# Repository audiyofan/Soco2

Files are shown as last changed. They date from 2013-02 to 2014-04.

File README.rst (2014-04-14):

=========================
SOCO2 PUSH PULL AMPLIFIER
=========================

Project authors:

- Pascal Benoist
- Grégoire Hubert
- Christophe Dedessus Les Moutier
- Yves Monmagnon

See http://audiyofan.org 

More information here http://www.audiyofan.org/forum/viewtopic.php?f=60&t=8371

Presentation
------------

Soco2 is a valve push-pull type amplifier delivering 10W in 8ohms with a low output impedance. It uses cheap Russian 6C19Π low impedance triodes as output valve and can be used without global feedback.

The built_version
------------------

The project was made on printed circuit board ( all files are included in Kicad folder )

This version does not use the PNK,

And the 6S19P's CCS is decoupled and has zener protection that prevents slippage cathode voltage on the higer swing

Power is succinct and yet respects the constants time

Local feedback of -1 dB, improve the damping factor

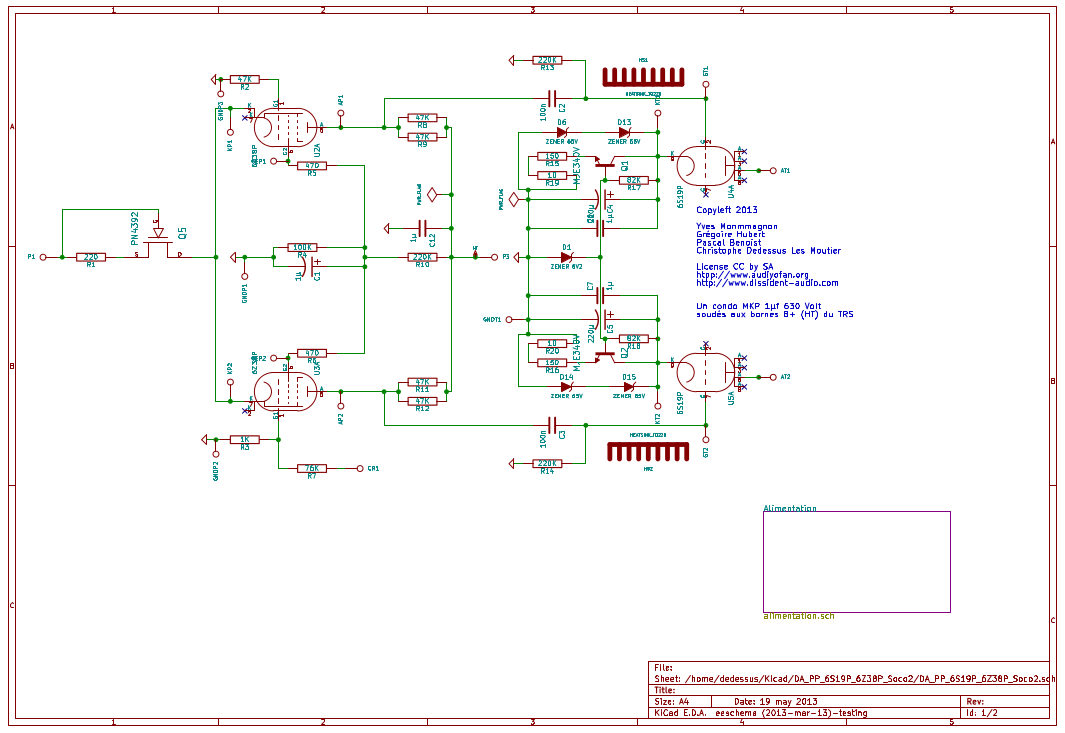
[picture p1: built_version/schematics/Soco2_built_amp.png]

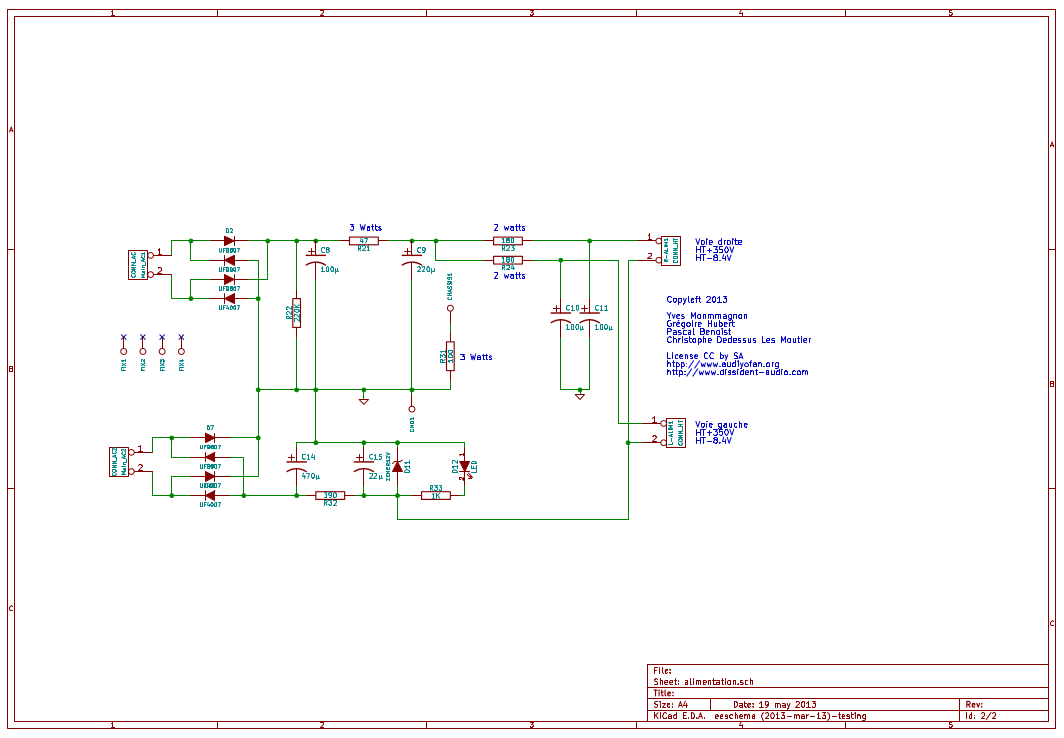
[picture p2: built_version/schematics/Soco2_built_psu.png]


Warning
-------

This schematic implies the use of **lethal voltages**. Maximum precautions must be observed when working with this kind of high voltages. Authors are **not** responsible in any way for any problems, damages or injuries that would result in the making of the work and / or use of this schematic (see LICENCE file).

Results
-------

Realisations emitted very natural, detailed and transparent sound with nice deep bass using speakers as low as 90dB/W/m. Measures showed -74dB THD for 1/2W output and -65dB THD for 1W (H2 and H3) with matched tubes. Output can reach 13W with -40dB THD in 8Ω. 
    
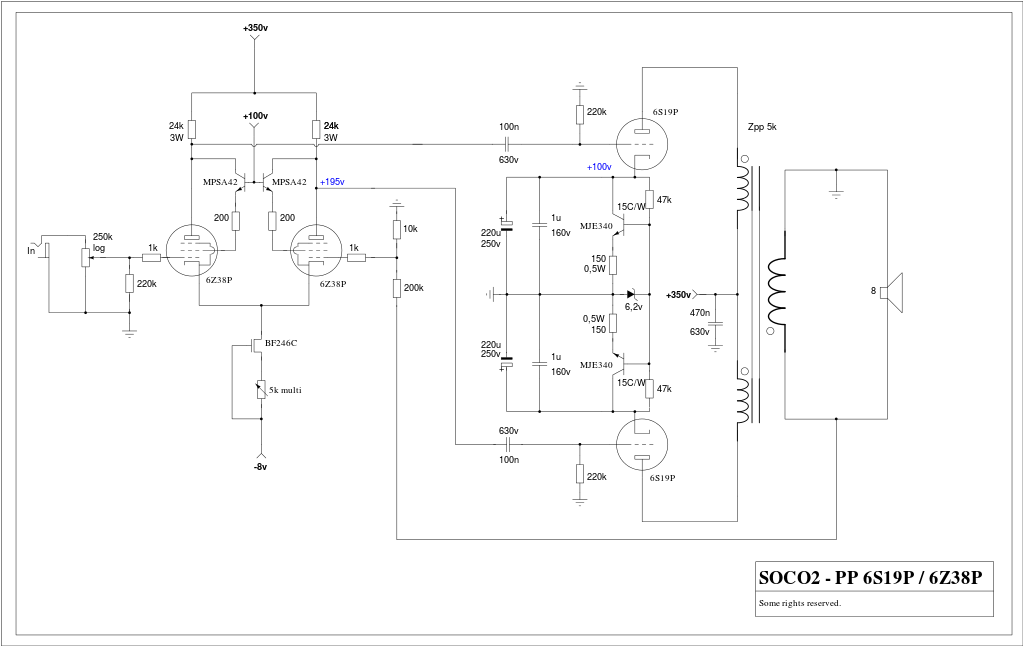
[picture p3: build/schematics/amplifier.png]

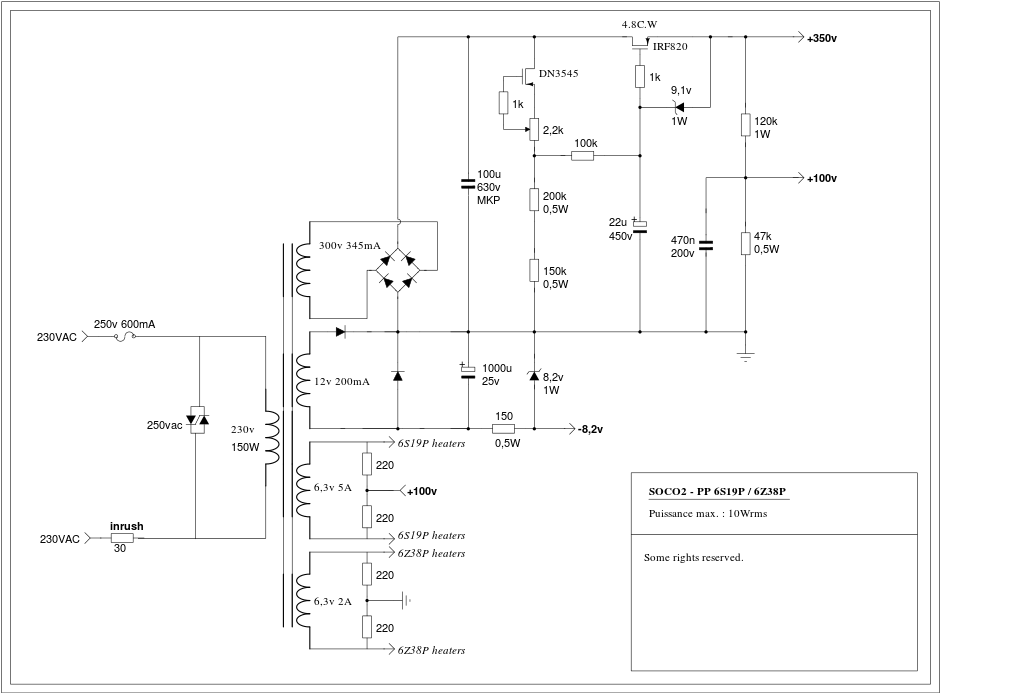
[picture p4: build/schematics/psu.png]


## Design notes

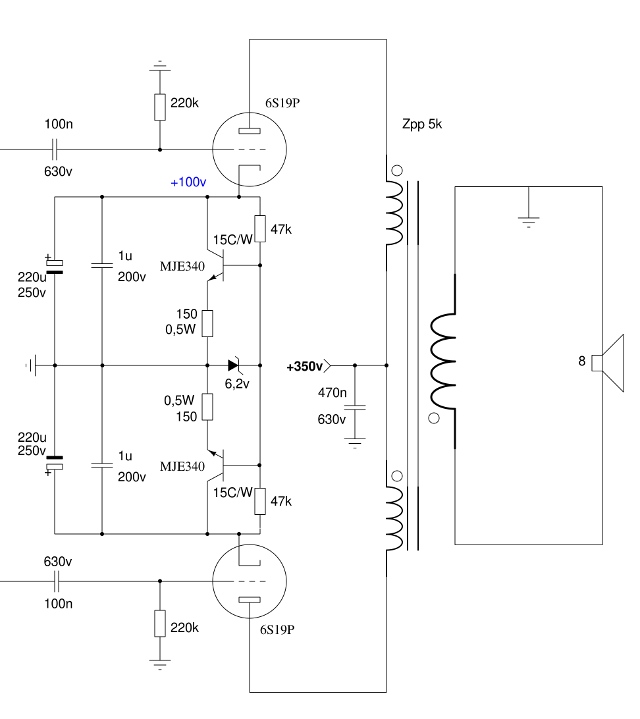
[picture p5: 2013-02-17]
build/schematics/power.png

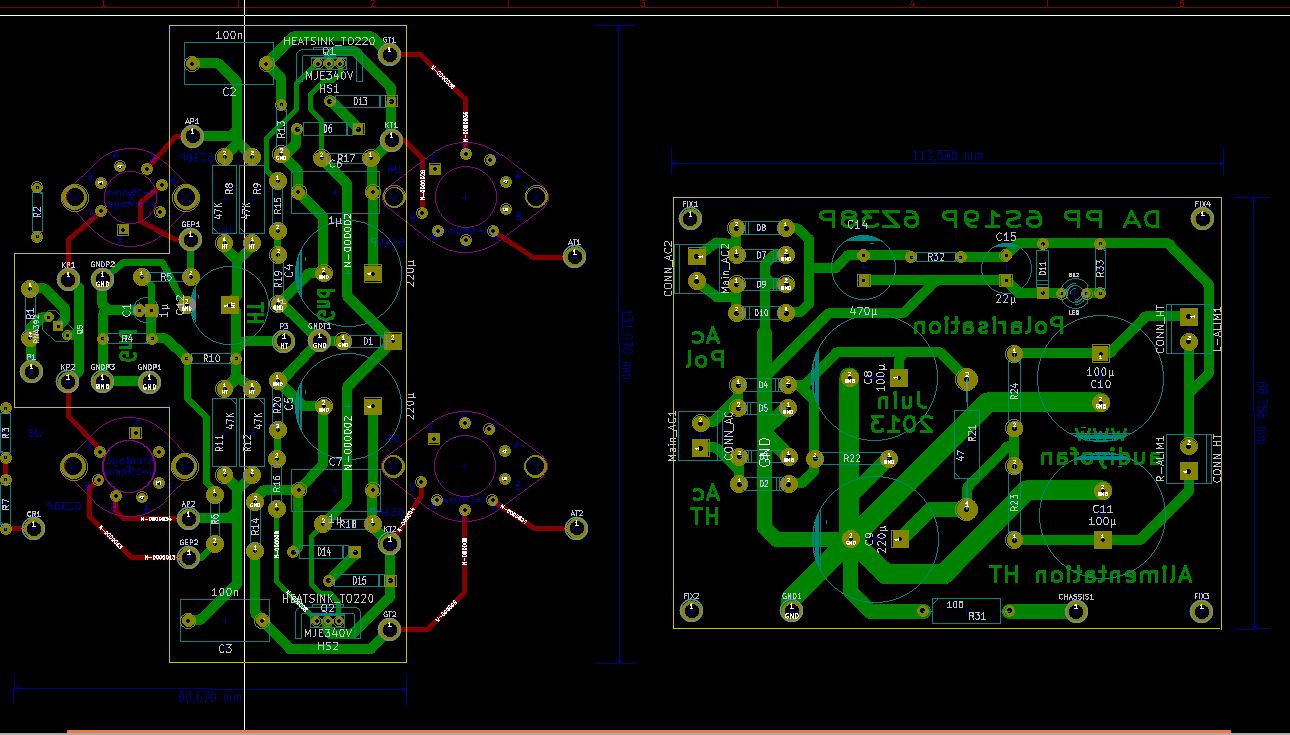
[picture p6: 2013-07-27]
built_version/Images/DA_Soco2_PCB.png

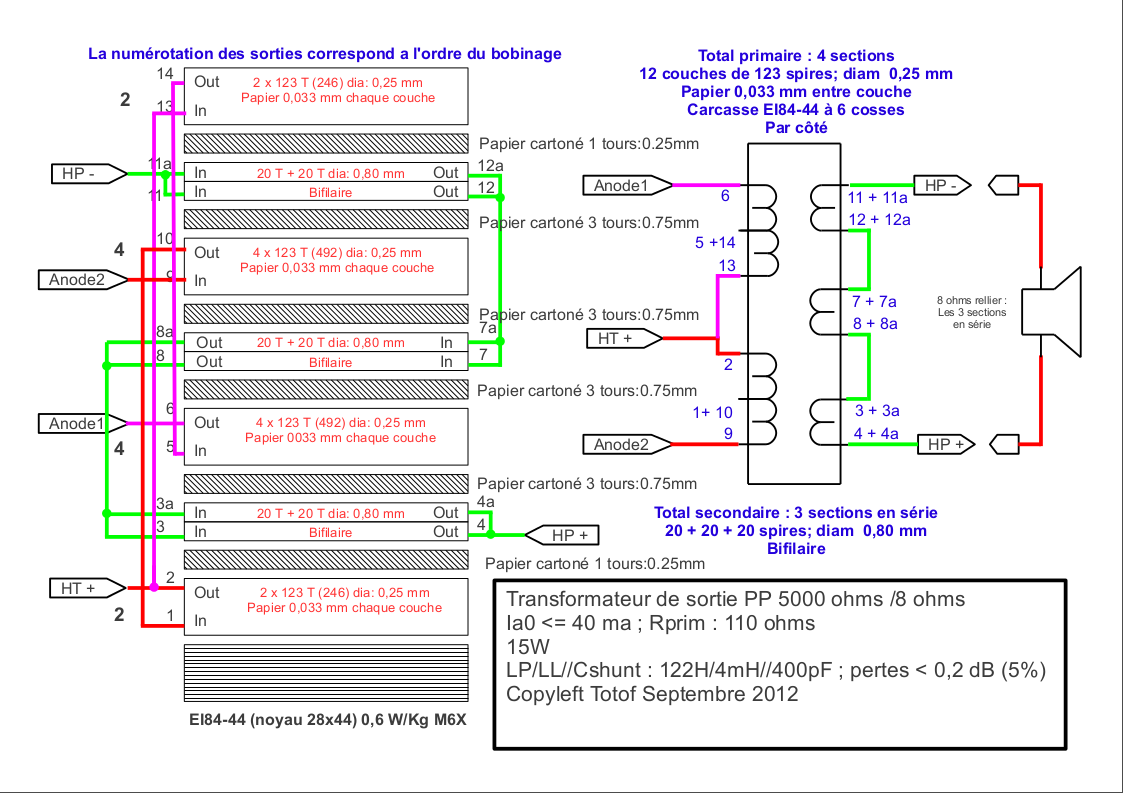
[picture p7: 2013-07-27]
built_version/Images/Calepinage_TRS_6S19P_6Z38P_final.png

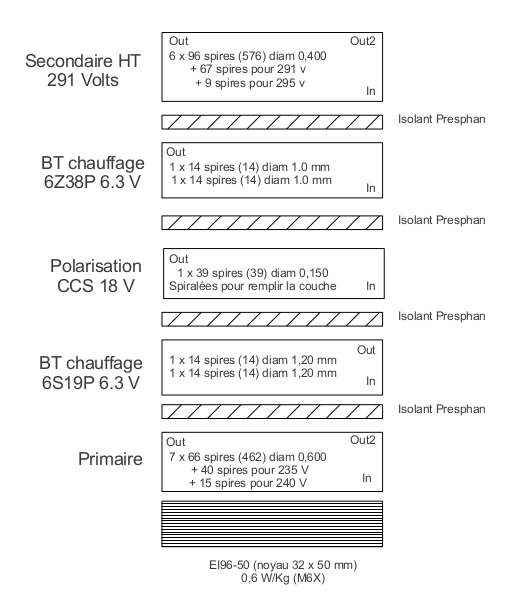
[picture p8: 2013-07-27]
built_version/Images/Calepinage TA .png

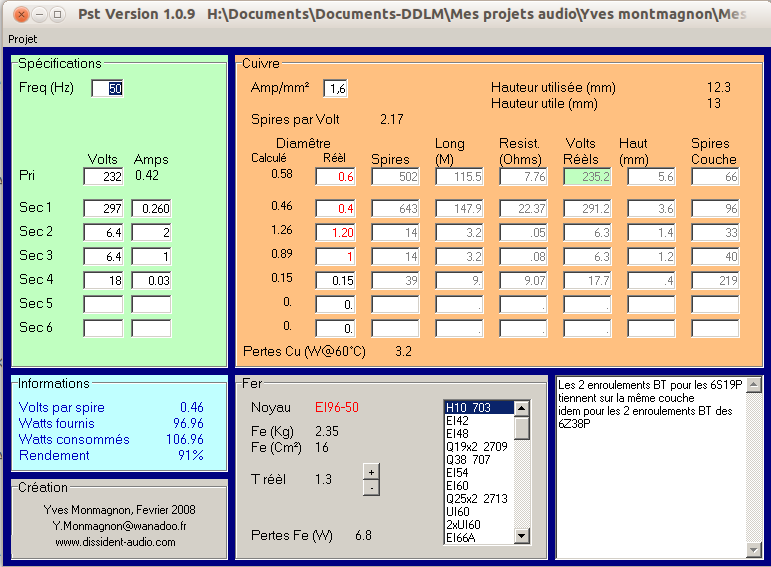
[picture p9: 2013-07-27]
built_version/Images/TA DA PP 6S19P 6Z38P PSX.png

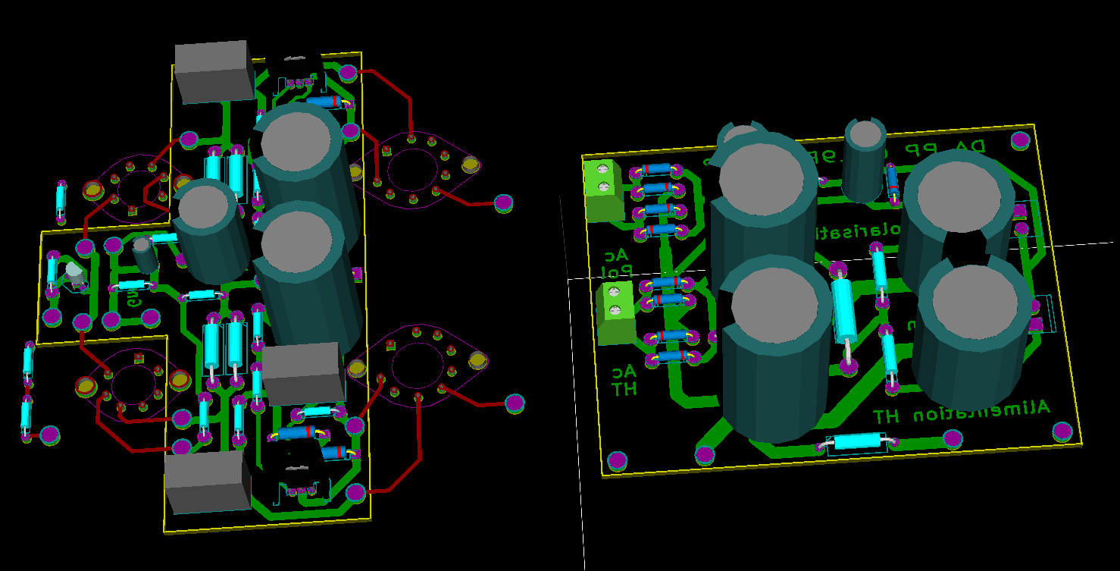
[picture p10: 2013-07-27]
built_version/Images/DA_Soco2_3D.png

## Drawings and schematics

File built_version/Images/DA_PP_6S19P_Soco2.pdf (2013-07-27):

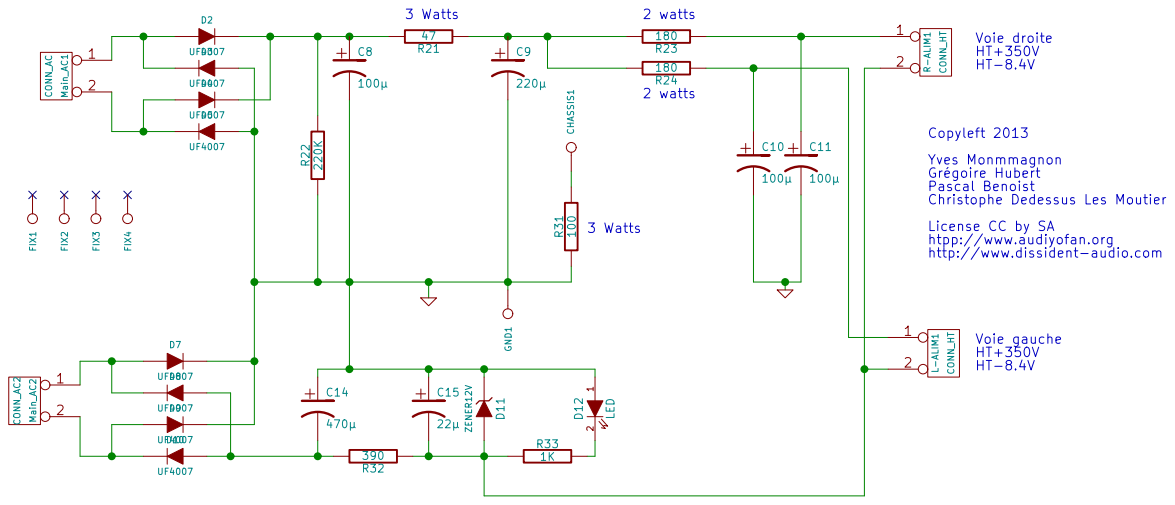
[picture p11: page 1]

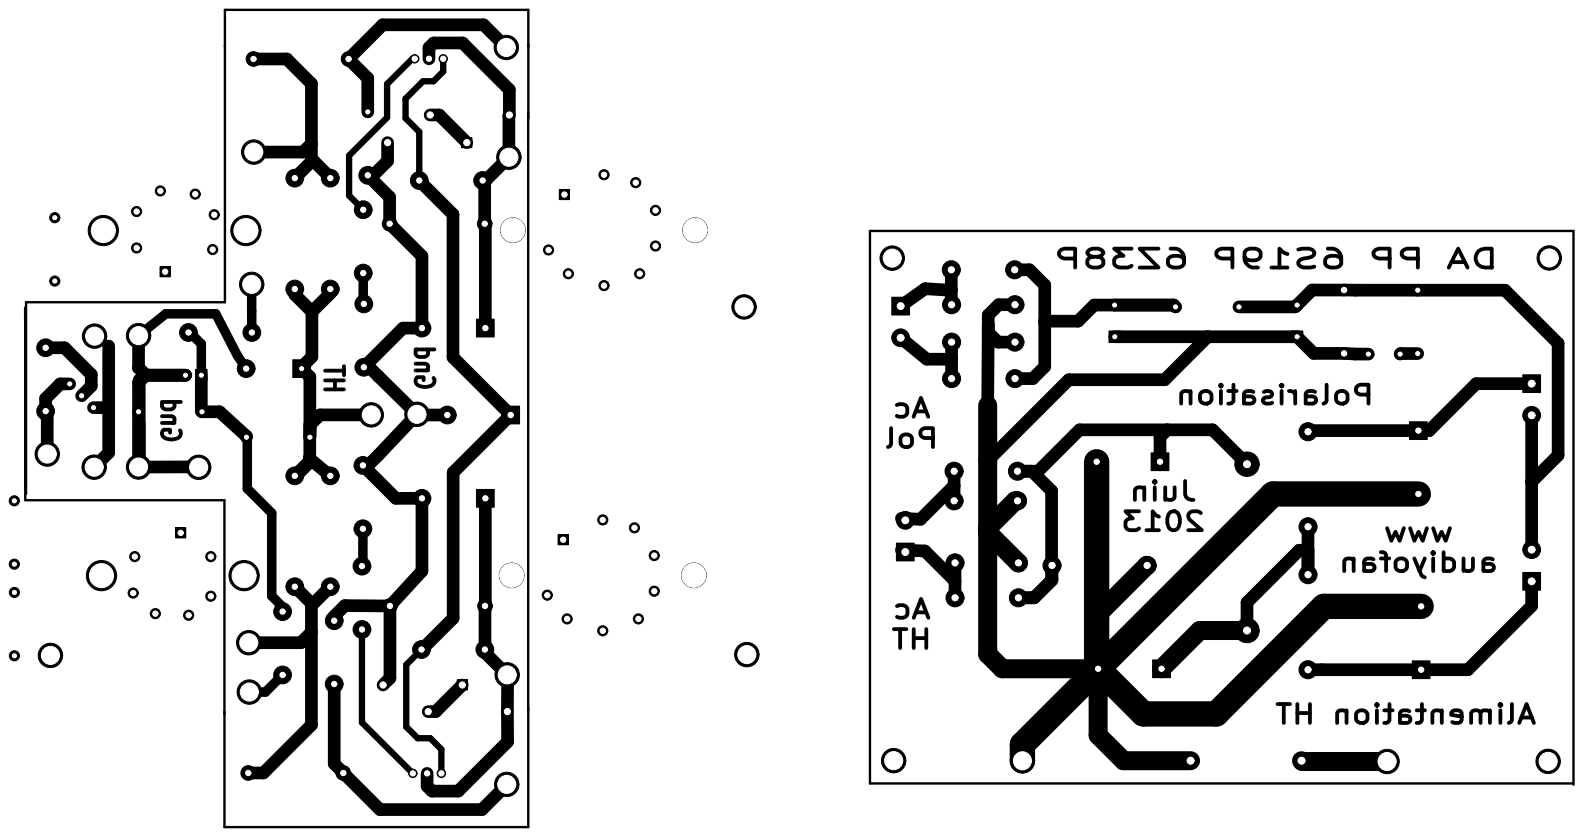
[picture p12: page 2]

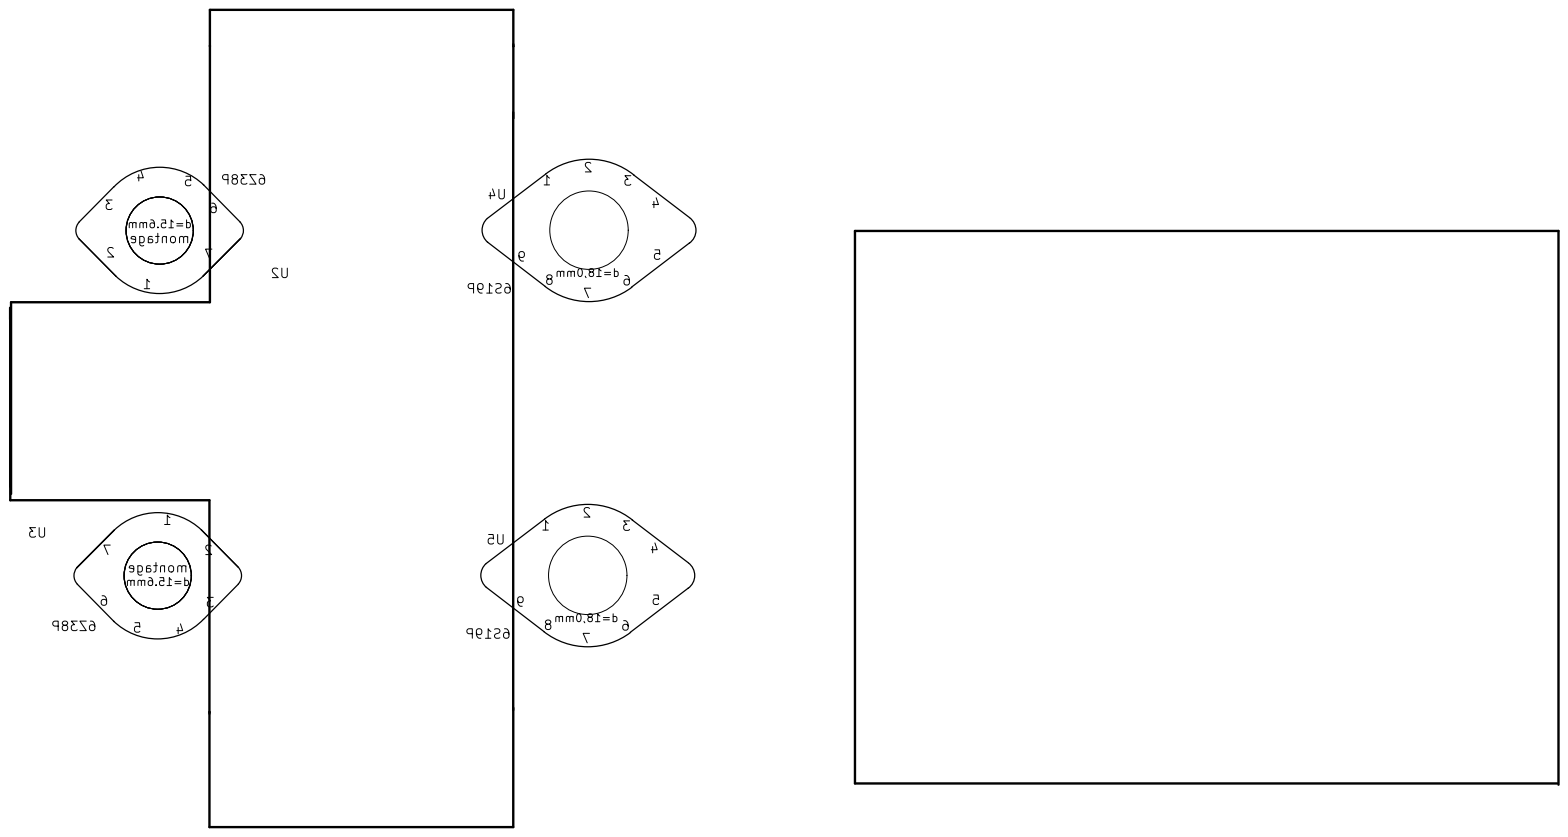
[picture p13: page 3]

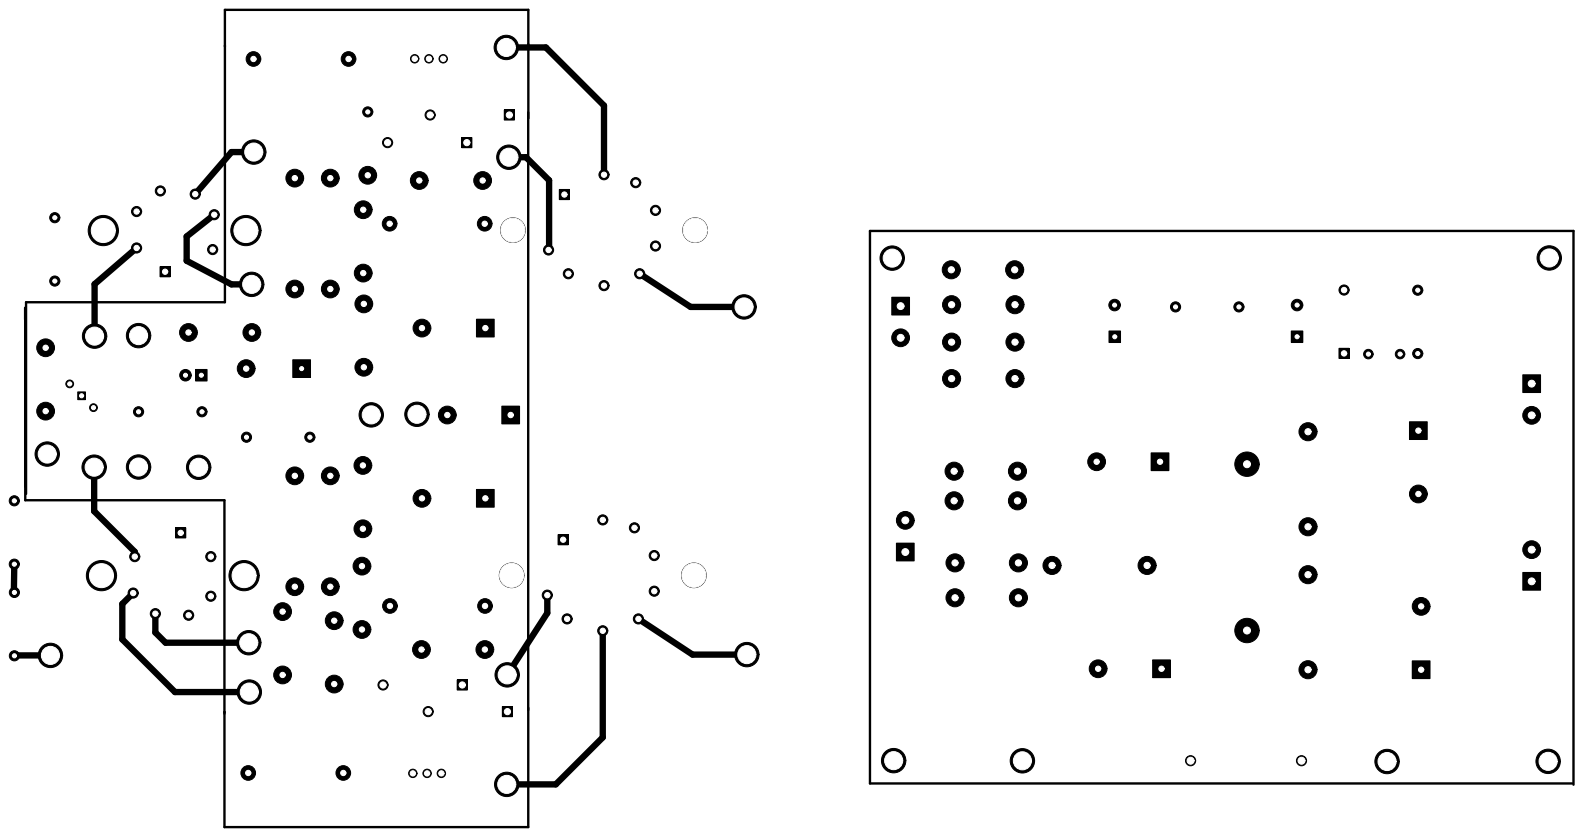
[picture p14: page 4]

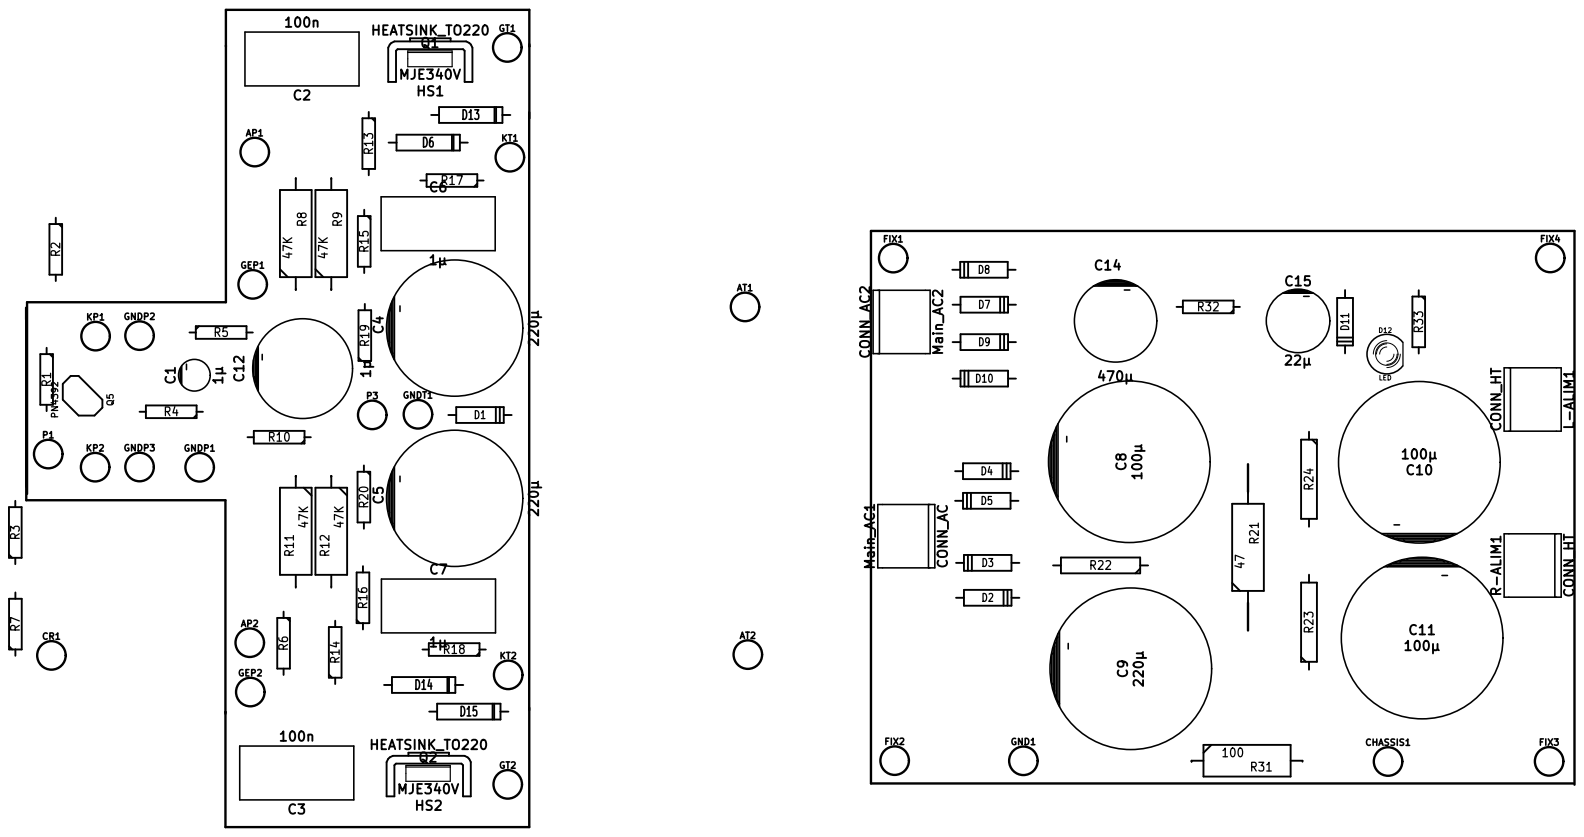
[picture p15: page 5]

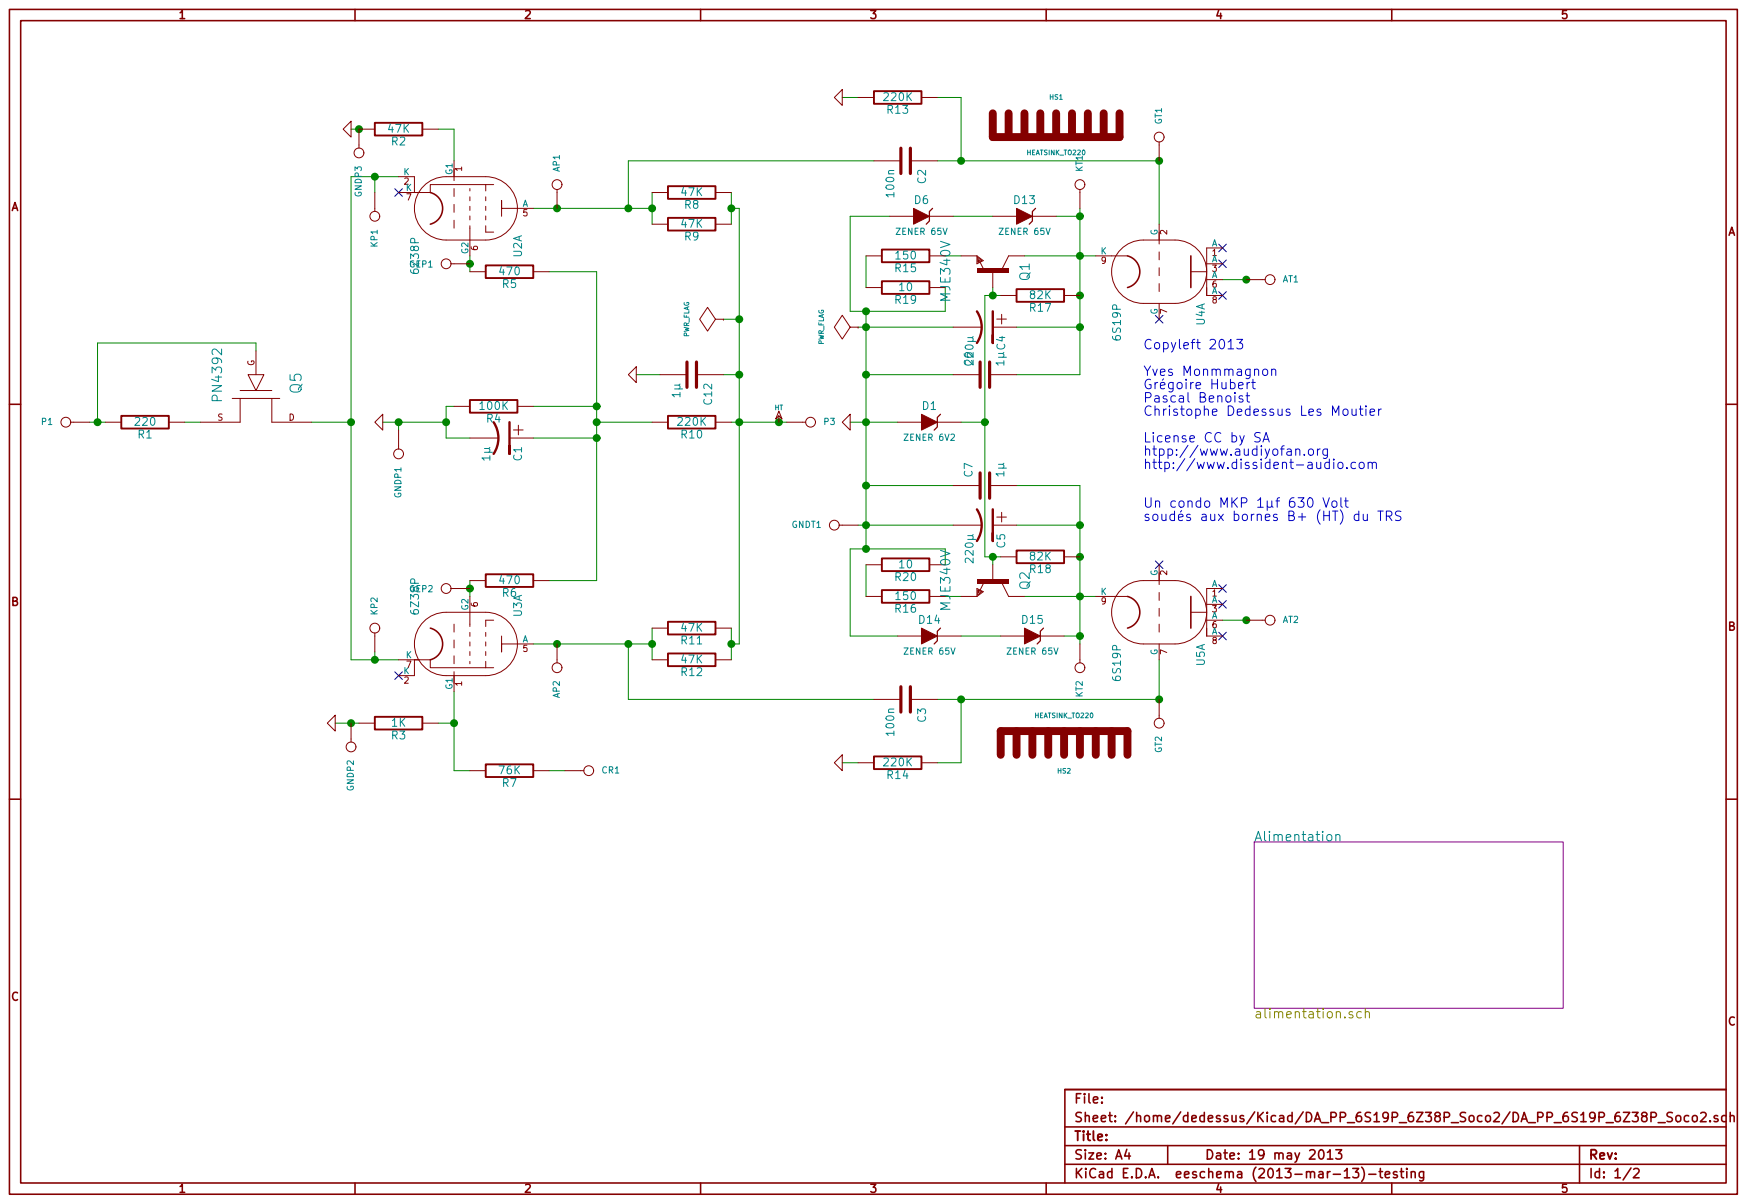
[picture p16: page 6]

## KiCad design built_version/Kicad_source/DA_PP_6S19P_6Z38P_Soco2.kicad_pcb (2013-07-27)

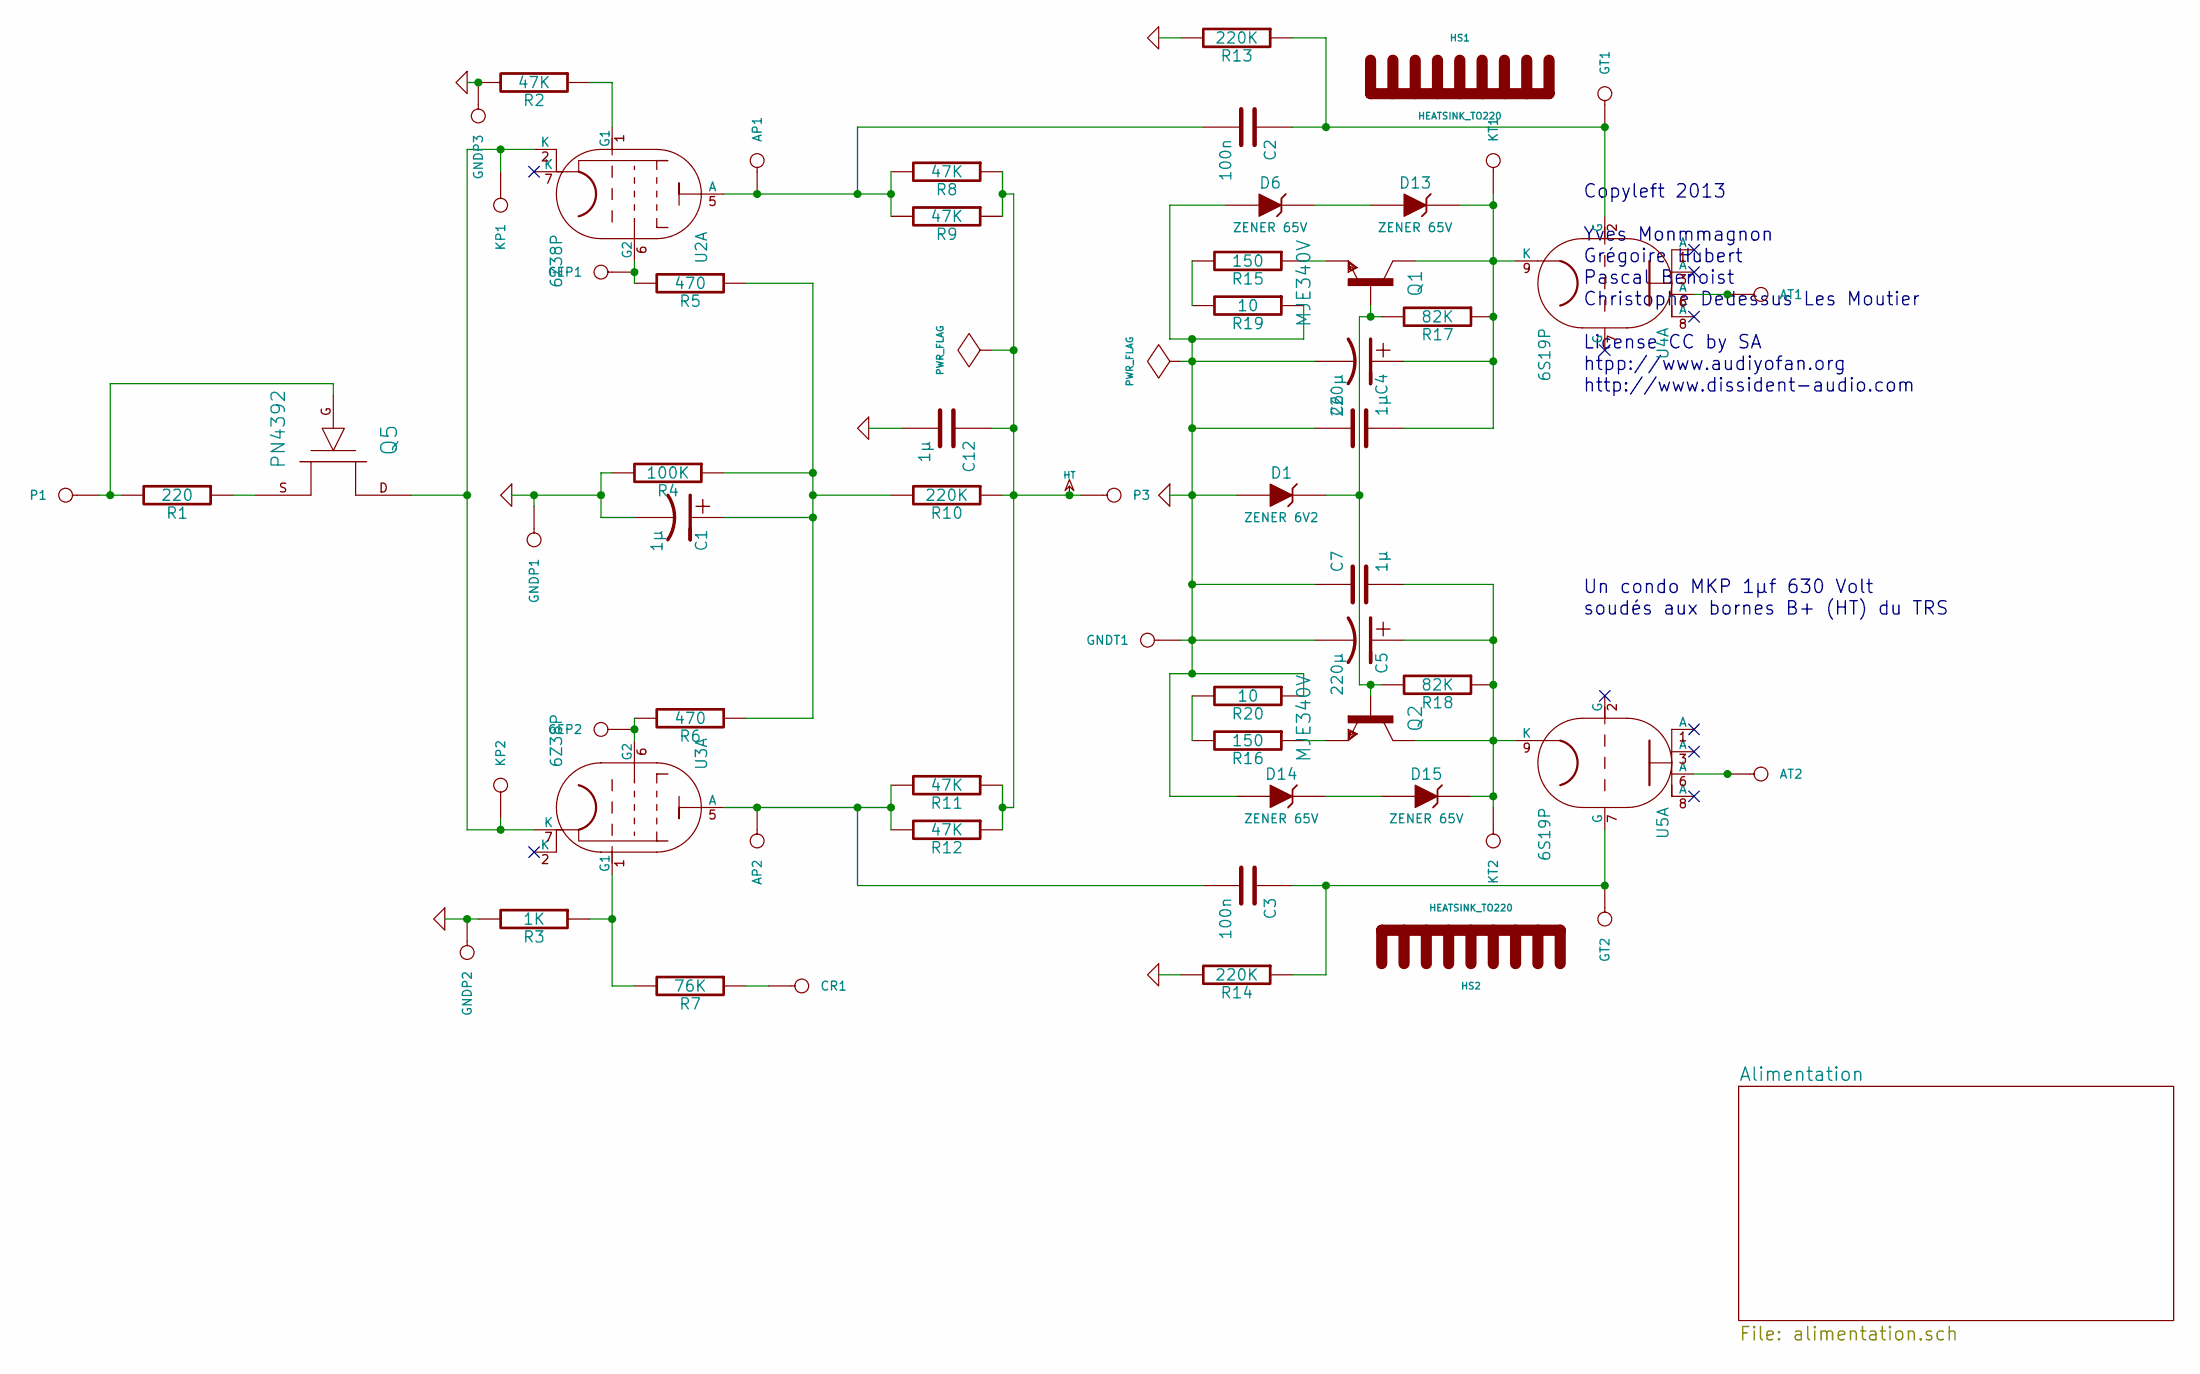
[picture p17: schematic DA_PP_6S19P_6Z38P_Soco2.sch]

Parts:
AP1: CONN_GNDE
AP2: CONN
AT1, AT2: CONN
C1, C6, C7, C12: 1µ
C2, C3: 100n
C4, C5: 220µ
CR1: CONN
D1: ZENER 6V2
D6, D13, D14, D15: ZENER 65V
GEP1, GEP2: CONN
GNDP1, GNDP2, GNDP3: CONN
GNDT1: CONN
GT1, GT2: CONN
HS1, HS2: HEATSINK_TO220
KP1, KP2: CONN
KT1, KT2: CONN
P1: CONN_VCC-
P3: CONN_HT
Q1, Q2: MJE340V
Q5: PN4392
R1: 220
R2, R8, R9, R11, R12: 47K
R3: 1K
R4: 100K
R5, R6: 470
R7: 76K
R10, R13, R14: 220K
R15, R16: 150
R17, R18: 82K
R19, R20: 10
U2, U3: 6Z38P; VALVE-NOVAL_P
U4, U5: 6S19P; VALVE-NOVAL_P

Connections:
GND: C1.2, C4.2, C5.2, C6.1, C7.1, C12.2, D1.1 (A), D6.1 (A), D14.1 (A), GNDP1.1, GNDP2.1, GNDP3.1, GNDT1.1, R2.2, R3.2, R4.2, R13.2, R14.2, R19.1, R20.1; also elsewhere on the board
HT: C12.1, P3.1, R8.1, R9.1, R10.1, R11.1, R12.1
unnamed: Q5.S, R1.1
unnamed: D1.2 (K), Q1.B, Q2.B, R17.2, R18.2
unnamed: C5.1, C7.2, D15.2 (K), KT2.1, Q2.C, R18.1, U5.9 (K)
unnamed: R15.2, R19.2
unnamed: Q1.E, R15.1
unnamed: R16.2, R20.2
unnamed: Q2.E, R16.1
unnamed: C3.1, GT2.1, R14.1, U5.7 (G)
unnamed: CR1.1, R7.1
unnamed: AP1.1, C2.2, R8.2, R9.2, U2.5 (A)
unnamed: GEP2.1, R6.2, U3.6 (G2)
unnamed: GEP1.1, R5.2, U2.6 (G2)
unnamed: AT1.1, U4.6 (A)
unnamed: D6.2 (K), D13.1 (A)
unnamed: AT2.1, U5.6 (A)
unnamed: D14.2 (K), D15.1 (A)
unnamed: R2.1, U2.1 (G1)
unnamed: R3.1, R7.2, U3.1 (G1)
unnamed: C4.1, C6.2, D13.2 (K), KT1.1, Q1.C, R17.1, U4.9 (K)
unnamed: C1.1, R4.1, R5.1, R6.1, R10.2
unnamed: KP1.1, KP2.1, Q5.D, U2.2 (K), U3.7 (K)
unnamed: P1.1, Q5.G, R1.2
unnamed: AP2.1, C3.2, R11.2, R12.2, U3.5 (A)
unnamed: C2.1, GT1.1, R13.1, U4.2 (G)

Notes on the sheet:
Un condo MKP 1µf 630 Volt soudés aux bornes B+ (HT) du TRS
Copyleft 2013 Yves Monmmagnon Grégoire Hubert Pascal Benoist Christophe Dedessus Les Moutier License CC by SA htpp://www.audiyofan.org http://www.dissident-audio.com

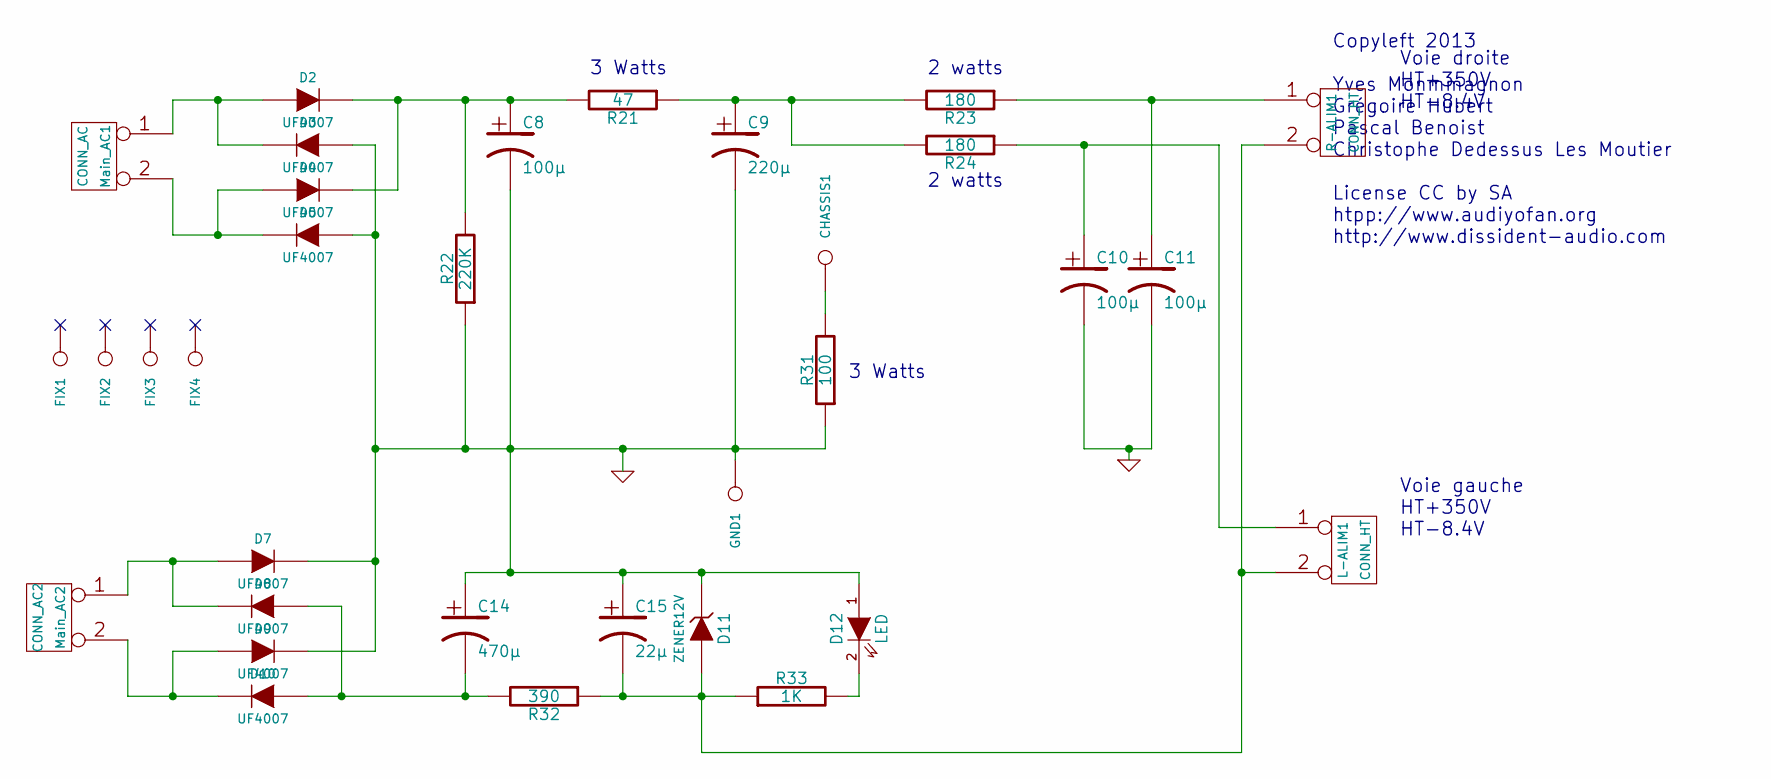
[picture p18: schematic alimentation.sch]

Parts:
C8, C10, C11: 100µ
C9: 220µ
C14: 470µ
C15: 22µ
CHASSIS1: CONN_CHASSIS
D2, D3, D4, D5, D7, D8, D9, D10: UF4007
D11: ZENER12V
D12: LED
FIX1, FIX2, FIX3, FIX4: FIX
GND1: CONN_GND
L-ALIM1: CONN_HT
Main_AC1: CONN_AC
Main_AC2: CONN_AC2
R21: 47
R22: 220K
R23, R24: 180
R31: 100
R32: 390
R33: 1K
R-ALIM1: CONN_HT

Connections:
GND: C8.2, C9.2, C10.2, C11.2, C14.1, C15.1, D3.1 (A), D5.1 (A), D7.2 (K), D9.2 (K), D11.2 (K), D12.1 (A), GND1.1, R22.1, R31.1; also elsewhere on the board
unnamed: D7.1 (A), D8.2 (K), Main_AC2.1
unnamed: C14.2, D8.1 (A), D10.1 (A), R32.2
unnamed: D12.2 (K), R33.2
unnamed: C9.1, R21.1, R23.2, R24.2
unnamed: C8.1, D2.2 (K), D4.2 (K), R21.2, R22.2
unnamed: CHASSIS1.1, R31.2
unnamed: D4.1 (A), D5.2 (K), Main_AC1.2 (PM)
unnamed: C10.1, L-ALIM1.1, R24.1
unnamed: D9.1 (A), D10.2 (K), Main_AC2.2 (PM)
unnamed: C15.2, D11.1 (A), L-ALIM1.2 (PM), R32.1, R33.1, R-ALIM1.2 (PM)
unnamed: D2.1 (A), D3.2 (K), Main_AC1.1
unnamed: C11.1, R23.1, R-ALIM1.1

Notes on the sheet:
Voie gauche HT+350V HT-8.4V
3 Watts
2 watts
Voie droite HT+350V HT-8.4V
Copyleft 2013 Yves Monmmagnon Grégoire Hubert Pascal Benoist Christophe Dedessus Les Moutier License CC by SA htpp://www.audiyofan.org http://www.dissident-audio.com

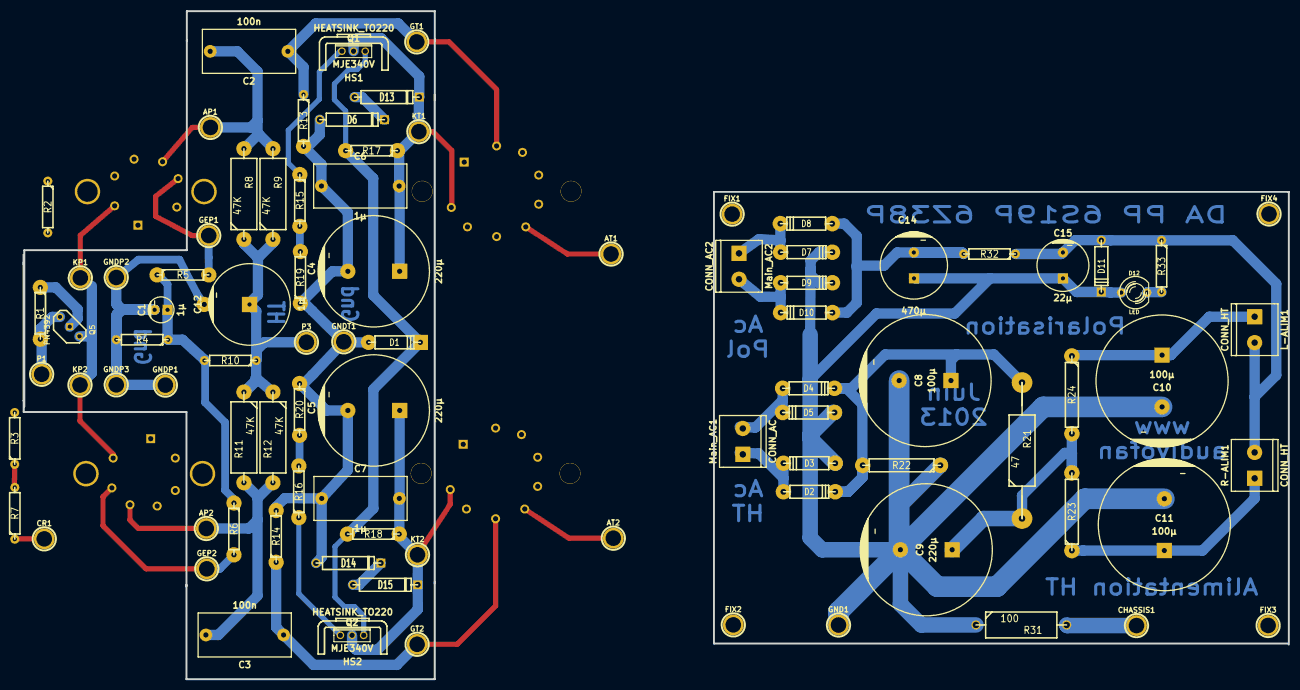
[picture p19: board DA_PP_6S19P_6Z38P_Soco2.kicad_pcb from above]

Board: 2 copper layers, 248.2 x 131.0 mm, 94 parts (0 on the bottom side), 38 nets.

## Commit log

2012-10-19 Current project status.
2012-12-22 Renamed schemas to schematics.
2012-12-23 1µF CCS bypass MKP ported to 200V.
2013-07-27 Adding a branch called totof
    [DA_PP_6S19P_6Z38P_Soco2.brd, DA_PP_6S19P_6Z38P_Soco2.kicad_pcb, DA_PP_6S19P_6Z38P_Soco2.sch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]
